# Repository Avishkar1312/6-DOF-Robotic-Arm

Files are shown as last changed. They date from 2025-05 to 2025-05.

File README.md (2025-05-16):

# 6-DOF Robotic Arm &#x1F916;

A robotic arm with 6 degrees of freedom made out of 3D printed parts. The software stack is primarily present in a Docker container setup in Raspberry Pi OS. It consists of a ROS2 pipeline written in Python with some C++ code in the Arduino IDE for controlling the stepper motors.

## Current Functionality:

* Currently only kinematic control has been established
* Individual joint angles can be altered using the Joint_State_Publisher_Gui and the respective changes in the configuration can be seen in the 3d model on Rviz2
* The desired joint angles can then be passed on to the hardware by pressing the "Enter" button in the GUI
* The hardware model receives the joint angles and aligns itself to match the configuration of the 3D model visualised in RViz

## Flow Chart:

Flowchart

## Pic of the model:

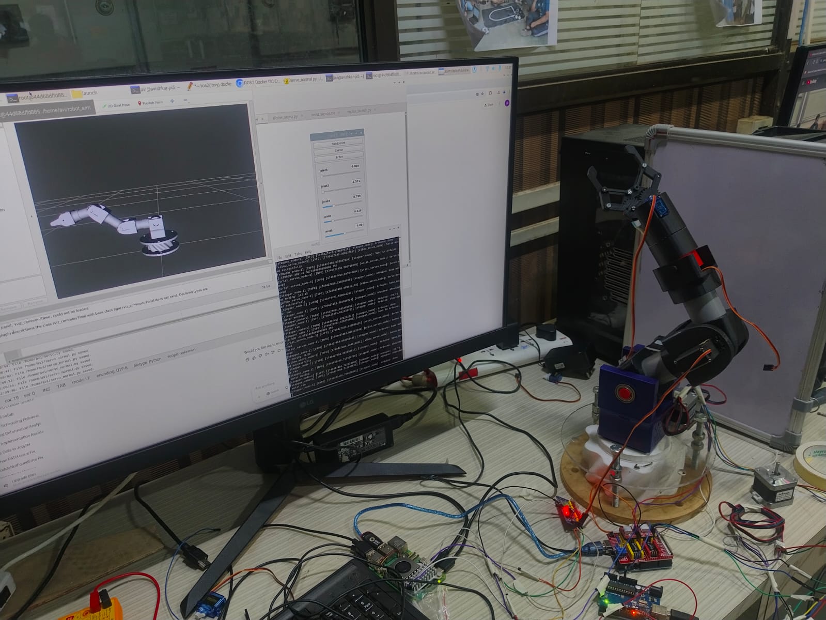
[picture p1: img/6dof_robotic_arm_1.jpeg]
Hardware model


## Softwares Used:

* SolidWorks
* Docker
* Raspberry Pi 5 OS
* Arduino IDE
* ROS2 Foxy
* RViz2

## Steps to replicate this identical model:

### I. CAD Model:

SolidWorks was used for creating the individual parts and assembling them together. If you want to use an identical model the cad files for all the individual parts and the assembly is present in the [Cad_files](Cad_files/) folder.

#### References used for modelling:

[RoTechnic Playlist](https://www.youtube.com/@roTechnic/playlists)

[Cycloidal Gear design](https://ewhiteowls.com/2022/02/the-ultimate-guide-to-design-cycloidal-drives-the-beating-heart-of-robotic-arms/)

[Modelling the robotic arm](https://www.youtube.com/playlist?list=PLeEzO_sX5H6TBD6EMGgV-qdhzxPY19m121)

After you have assembled it on SolidWorks, you will have to assign the proper coordinate frames to each joint(Tutorial for this is present in the references).

Once everything in  modelling is done, we will generate a URDF file for the model. For this, use the [Solidworks to URDF Converter](https://wiki.ros.org/sw_urdf_exporter) which will create a ROS package with your model in it.

We ultimately want a ROS2 package so we would use this application to convert it into a ROS2 package 

[ROS2 URDF Converter](https://wiki.ros.org/sw_urdf_exporter)

### II. Setting up Pi Environment:

Use Raspberry Pi Imager to flash the Raspberry Pi 5 OS image onto a USB drive. Then insert the USB into the Raspberry Pi 5 to boot from it
Configure the Pi accordingly. Some key configuration steps to follow:

1. Go into Raspi-Config
2. Enable SSH, VNC, and I2C
3. Enable the serial hardware port
4. Change the forwarding from Wayland to X11

#### Clone the repo:

```bash
git clone https://github.com/Avishkar1312/6-DOF-Robotic-Arm.git
```

#### Go into the folder and build the Docker image

```bash
docker build -t your-image-name .  #Keep the name according to your choice
```
### III. Running the simulation:

#### In one terminal run 

```bash
xhost +local:root
```
This command allows the root user to access the X server. This would be essential to see the GUI output of Rviz2 on the screen.

#### In another terminal, go into your work folder(in this case)

```bash
cd 6-DOF-Robotic-Arm-main 
```

#### Run the container:

> ⚠️ **Disclaimer:** Connect the Arduino with Raspberry Pi5 before running the command
```bash
docker run -it --rm --env DISPLAY=:0 --volume /tmp/.X11-unix:/tmp/.X11-unix --volume /path/on/host:/path/in/container --device /dev/ttyACM0 your_container_name
```

#### Navigate to the working directory and source the ros2 environment

```bash
source /opt/ros/foxy/setup.bash
```

#### Build the packages

```bash
colcon build 
```
This will create install,build and log folders in your workspace

#### Source the workspace 

```bash
source install/setup.bash
```
#### Launch the GUI and RViz window

```bash
ros2 launch final_arm_urdf launch.py 
```

You would now be able to interact with the simulation using the Joint_State_Publisher_GUI

### IV. Setting up the circuit connections

For the circuit diagrams, follow the images given in the [Circuit_diagrams](Circuit_diagrams/) folder. Copy the code given in the [Arduino_codes](Arduino_codes/) folder and paste it into your Arduino IDE. Upload this code into your respective Arduino.

After completing the circuit and connecting the motors, follow the further instructions to run the motor

1. Execute the steps of part III. (running the simulation) same as mentioned
2. Open a new terminal and go into the Docker container

```bash
docker ps 
```
Then copy the generated container id and use it in 

```bash
docker exec -it <container_id> bash # Paste your container id 
```

This will take you to the same container. Now navigate again to your workspace and source it. After all this, run the following command

```bash
ros2 launch raspi motor_launch.py
```
This will launch the nodes for each motor at once.

The hardware model is also ready to be executed. On pressing the "Enter" button on the GUI the specific configuration joint angles would be passed onto the hardware.

## Hardware Configuration:

| Joint | Gear type & Ratio | Motor |
|---|---|---|
| Base Joint | Cycloidal Gear (1:10) | NEMA 17 Stepper motor |
| Shoulder Joint | Snug fit(1:3.71) | NEMA 17 Stepper motor with gearbox |
| Elbow Joint | Snug Fit( Internal gears in servo)(1:1) | Metal geared servo motor |
| Wrist joints(3) | Snug Fit( Internal gears in servo)(1:1) | Plastic geared servo motor |

## Future Work to be done:

* Dynamic control is to be added
* Thinking of venturing into upper-level control, such as voice control.

## Open for more suggestions

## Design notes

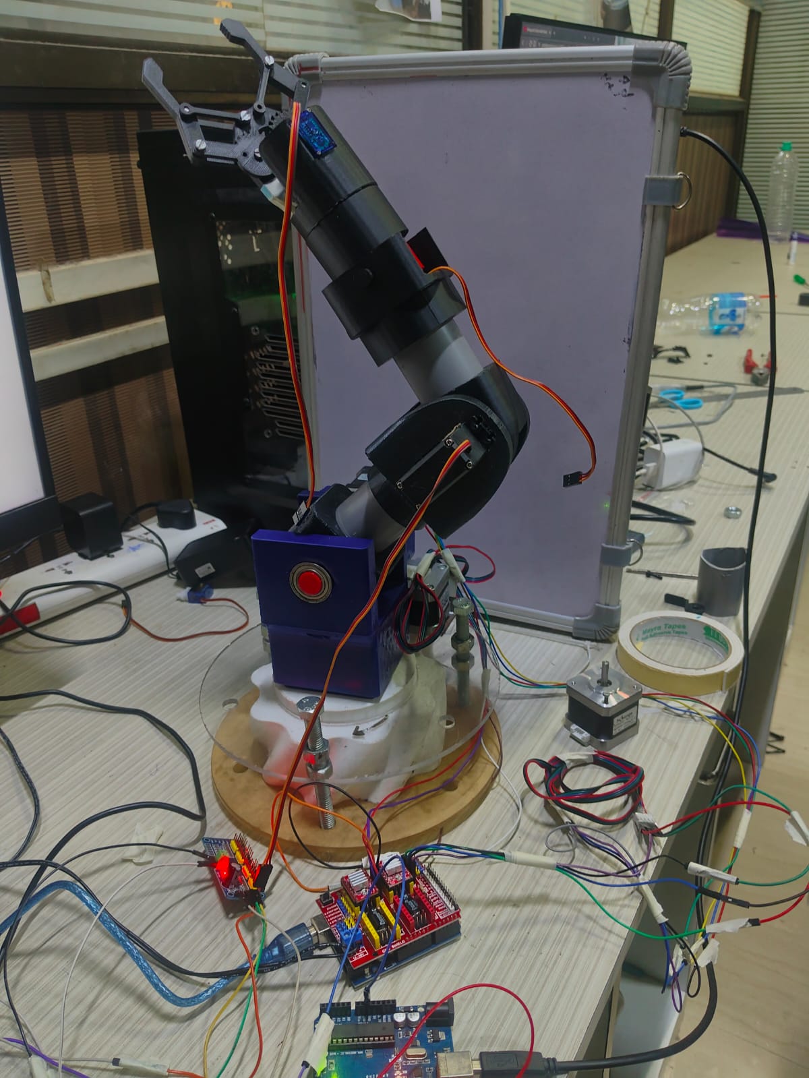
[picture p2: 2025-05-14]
img/6dof_robotic_arm_2.jpeg

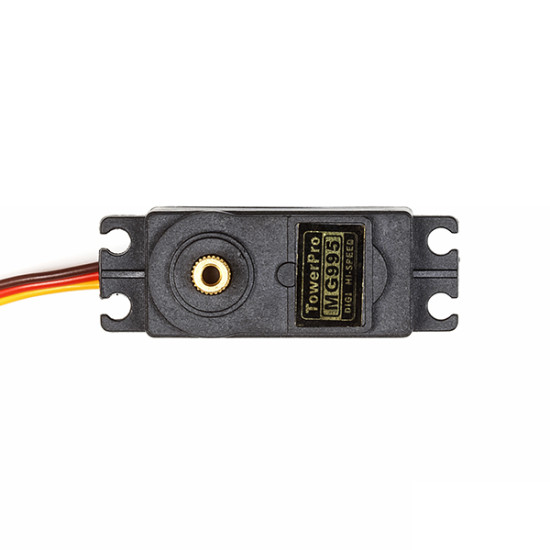
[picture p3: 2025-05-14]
img/servo_shoulder.jpg

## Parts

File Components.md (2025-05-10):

## Components List

| Component | Image | Quantity | Price  | Link |
|---|---|---|---|---|
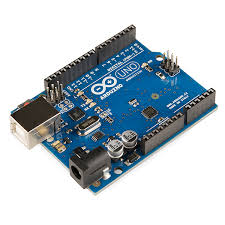
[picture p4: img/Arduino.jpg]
| Arduino Uno |  | 1 | ₹517  | [Buy](https://robu.in/product/arduino-uno-r3/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) |
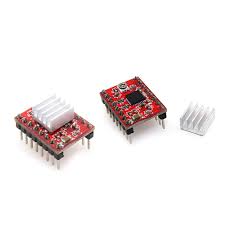
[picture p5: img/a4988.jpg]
| A4988 Stepper Driver|  | 2 | ₹61 | [Buy](https://robu.in/product/a4988-driver-stepper-motor-driver-standard-quality/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) |
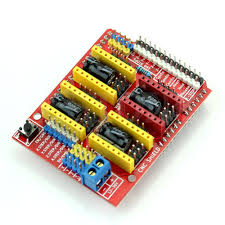
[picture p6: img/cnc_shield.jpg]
| CNC Shield V3 |  | 1 | ₹110 | [Buy](https://robu.in/product/cnc-shield-v3-engraving-machine-3d-printer-a4988-drv8825-driver-expansion-board/) |
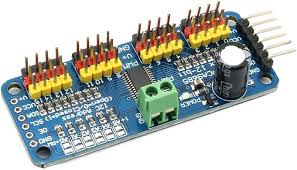
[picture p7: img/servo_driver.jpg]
| Servo Driver(PCA9685) |  | 1 | ₹228 | [Buy](https://robu.in/product/16-channel-12-bit-pwmservo-driver-i2c-interface-pca9685-arduino-raspberry-pi/) |
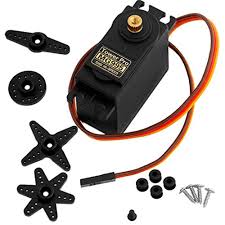
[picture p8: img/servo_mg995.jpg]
| Servo MG995(360 degrees) |  | 1 | ₹620 | [Buy](https://www.amazon.in/Robodo-TowerPro-MG995-Continuous-rotation/dp/B07DDKMM3J) |
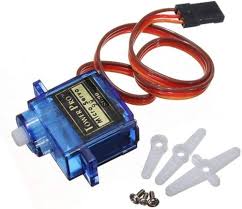
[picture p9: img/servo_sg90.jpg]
| Servo SG90(180 degrees) |  | 3 | ₹870 | [Buy](https://robu.in/product/towerpro-sg90-9g-mini-servo-9-gram/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) |
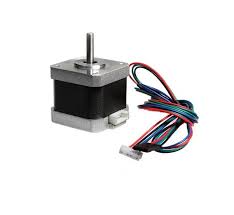
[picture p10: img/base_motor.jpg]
| Stepper motor (NEMA 17) |  | 1 | ₹681 | [Buy](https://robu.in/product/nema17-pr42hs40-1204af-02-4-2kg-cm-stepper-motor-d-type-shaft/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) |
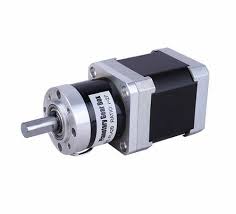
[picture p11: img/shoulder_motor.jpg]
| Stepper motor (NEMA 17-Gerabox(1:3.71)) |  | 1 | ₹3249 | [Buy](https://thinkrobotics.com/products/nema-17-planetary-gear-stepper-motor-100-1?variant=39604954693718) |
| Raspberry Pi5 8GB RAM |  | 1 | ₹8209 | [Buy](https://robu.in/product/raspberry-pi-5-model-8gb/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) |
| Raspi5 Heatsink |  | 1 | ₹456 | [Buy](https://robu.in/product/official-raspberry-pi-5-active-cooler/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) |
| Raspberry Pi5 Charger |  | 1 | ₹1149 | [Buy](https://robu.in/product/official-27w-usb-c-pd-power-supply-for-raspberry-pi-5-black/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) |
| USB(32GB) |  | 1 | ₹359 | [Buy](https://www.amazon.in/SanDisk-Cruzer-Blade-Flash-Drive/dp/B005FYNT3G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) |
| HDMI to Micro-USB |  | 1 | ₹451 | [Buy](https://www.flipkart.com/darahs-micro-usb-cable-1-4-m-high-speed-hdmi-not-micro-usb-ethernet-1-4-meter/p/itm2af90483b95cd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) |
| 12V Adapter |  | 1 | ₹180 | [Buy](https://robocraze.com/products/12-volt-2-amp-power-adapter-ac-to-dc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) |
| Silicon Grease |  | 1 | ₹265 | [Buy](https://www.amazon.in/TetraClean-Dielectric-Automotive-Electricals-Electrical/dp/B08R3NXT3B) |
| Ball Bearing(15x28x7) |  | 2 | ₹209(for 4) | [Buy](https://robu.in/product/6902zz-bearing-15x28x7-shielded-miniature-ball-bearings-4pcs/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) |
| Jumper wires |  | 1 | ₹107 | [Buy](https://robu.in/product/male-to-female-jumper-wires-40-pin-40cm/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) |
| 3-D Printing Filament (PLA) |  | ... | ₹891 | [Buy](https://robu.in/product/pro-range-pla-filament-1-75mm-1-kg-spool-black/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) |

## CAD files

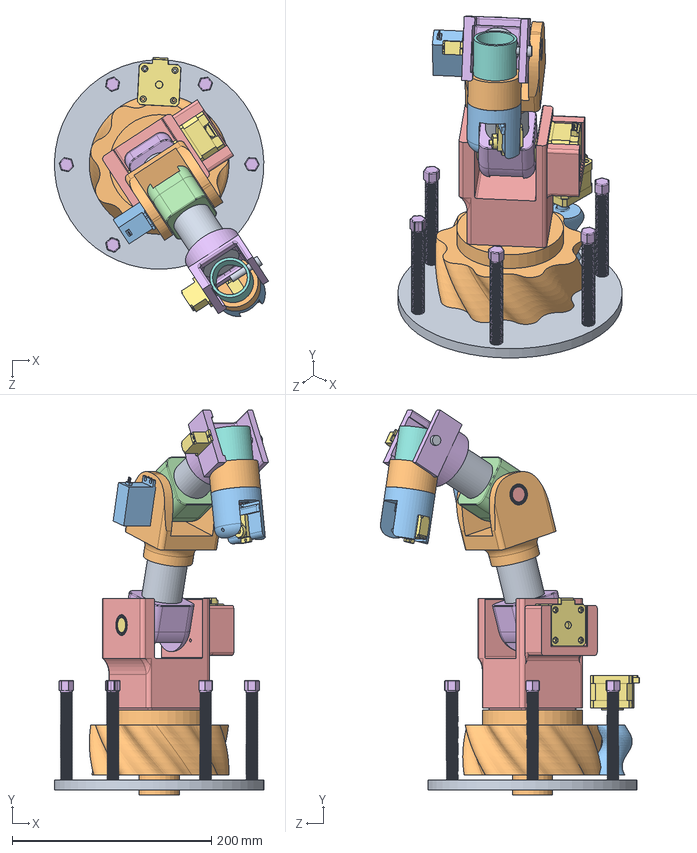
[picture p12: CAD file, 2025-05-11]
Cad_files/Robotic_Arm_final.SLDASM
214.6 x 386.0 x 259.9 mm
base_bottom
large_gear
small_gear
bottomstud
shoulder_mock1
final_shoulder
plug
instrument ball bearing_68_am x 2
arm x 2
elbow
mg995
elbow_extn_final
elbow_plug
wristholder
Servo SG90 x 3
pinpin
wrist _rotation_lid
blue_servo_mod_teeth
[4145] TowerPro SG90 Mini Servo-SunRobotics_in-Pt4
screw x 7
NEMA_17 x 2

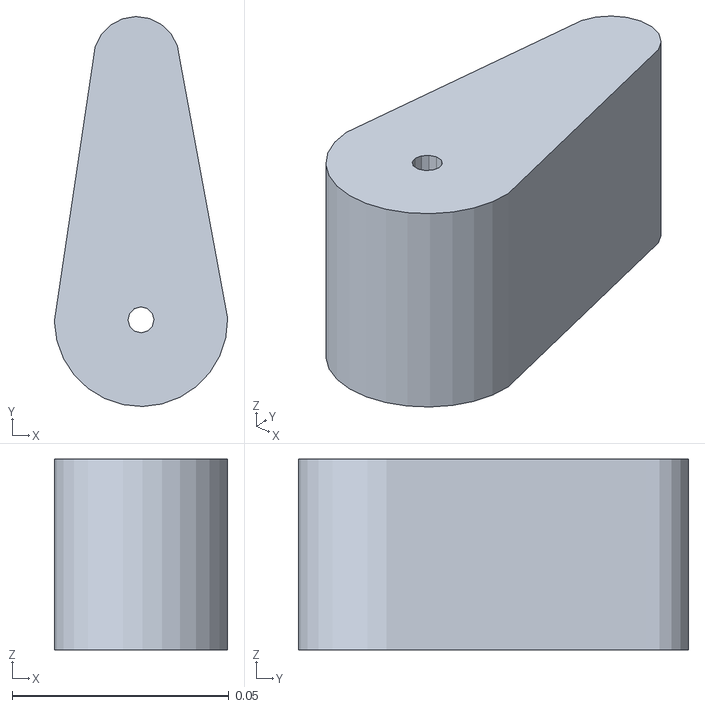
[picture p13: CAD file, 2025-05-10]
src/final_arm_urdf/meshes/collision/link5.STL
0.04 x 0.09 x 0.044

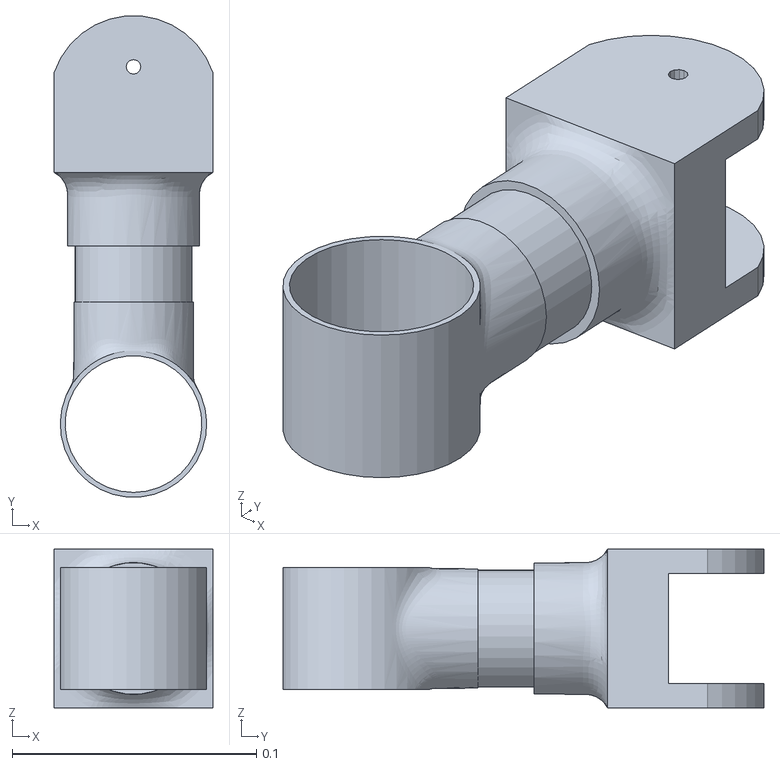
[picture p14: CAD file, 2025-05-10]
src/final_arm_urdf/meshes/visual/link4.STL
0.065 x 0.197 x 0.065

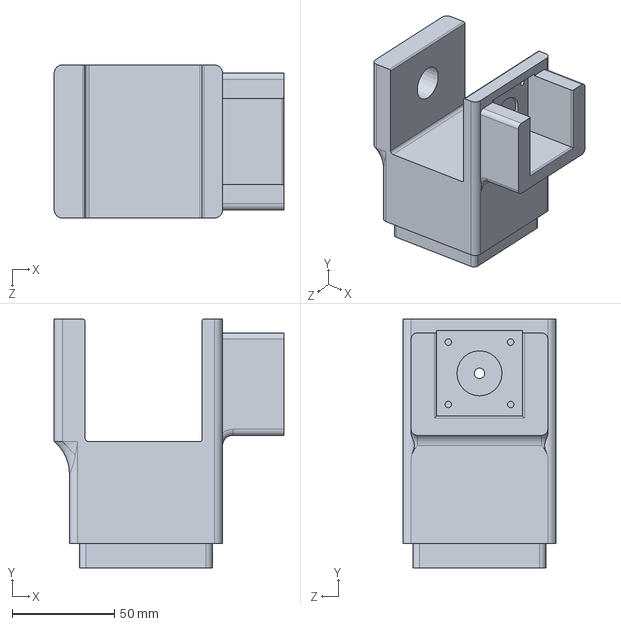
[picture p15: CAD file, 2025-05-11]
Cad_files/shoulder_mock1.SLDPRT
112.5 x 122.0 x 75.0 mm

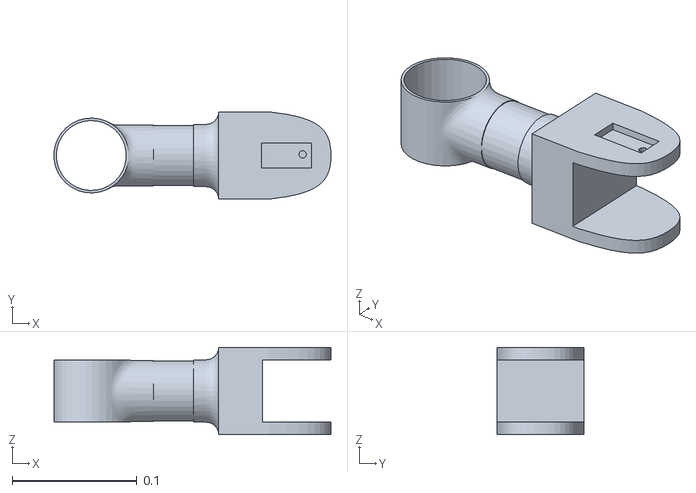
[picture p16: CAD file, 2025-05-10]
src/final_arm_urdf/meshes/collision/link3.STL
0.222 x 0.07 x 0.07

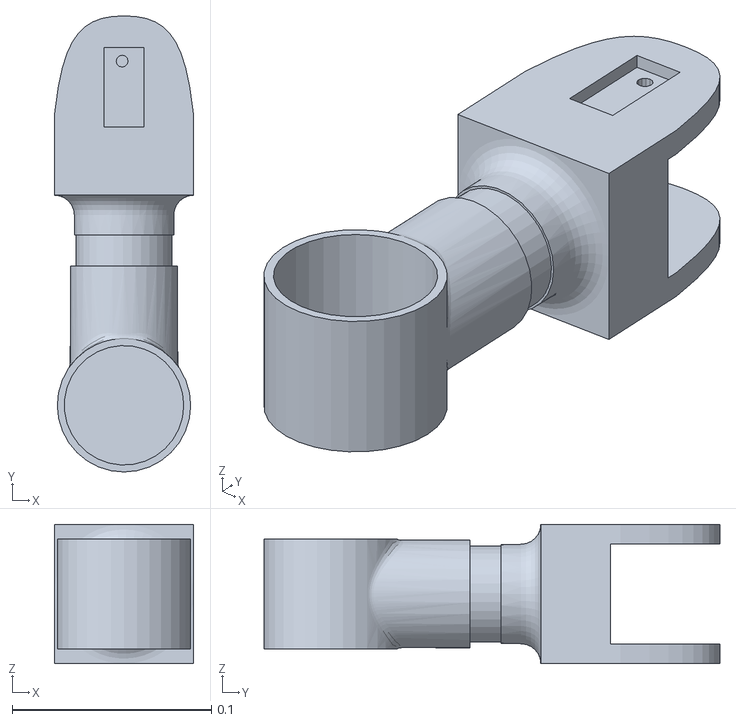
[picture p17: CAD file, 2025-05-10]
src/final_arm_urdf/meshes/visual/link2.STL
0.07 x 0.229 x 0.07

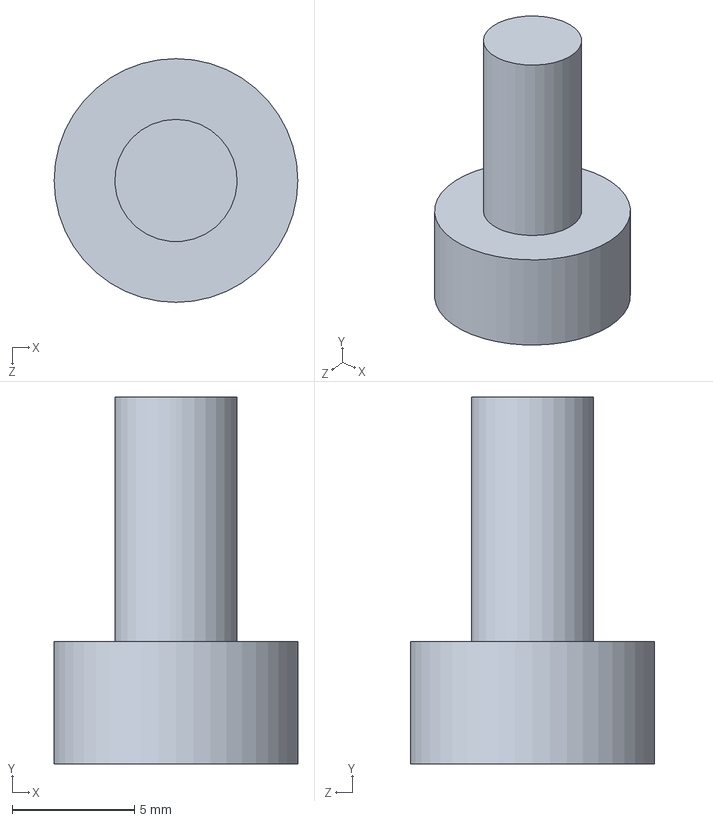
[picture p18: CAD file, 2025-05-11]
Cad_files/bottomstud.SLDPRT
9.96 x 15.0 x 9.96 mm

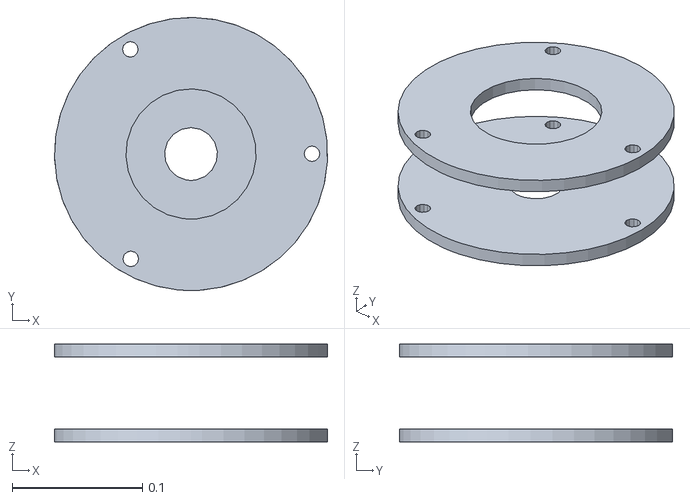
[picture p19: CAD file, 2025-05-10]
src/final_arm_urdf/meshes/collision/base_link.STL
0.21 x 0.21 x 0.075

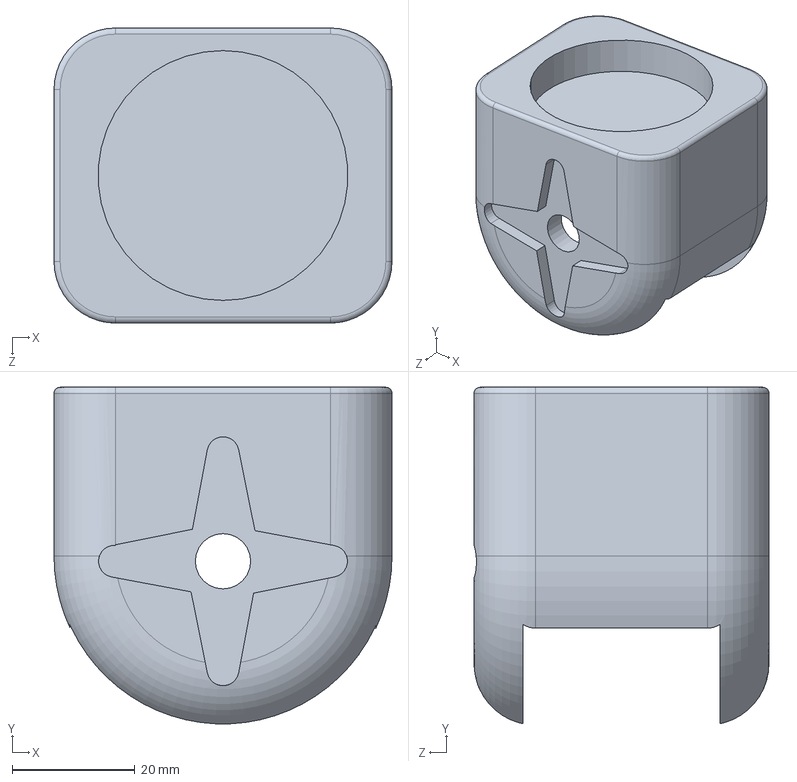
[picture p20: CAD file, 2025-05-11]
Cad_files/elbow_extn_final.SLDPRT
55.0 x 54.8 x 48.0 mm

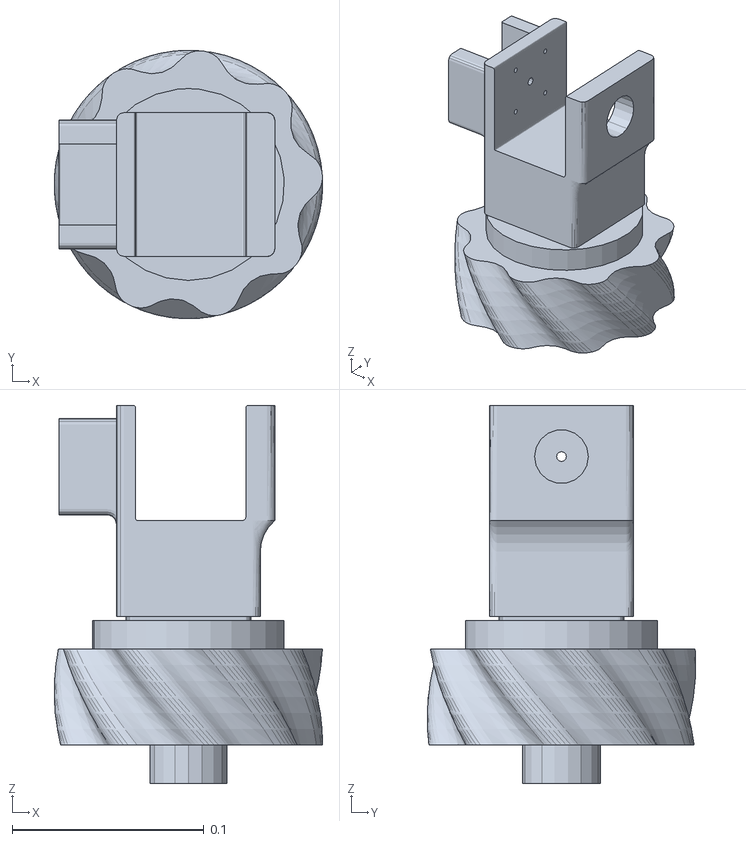
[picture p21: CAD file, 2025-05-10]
src/final_arm_urdf/meshes/visual/link1.STL
0.14 x 0.14 x 0.197

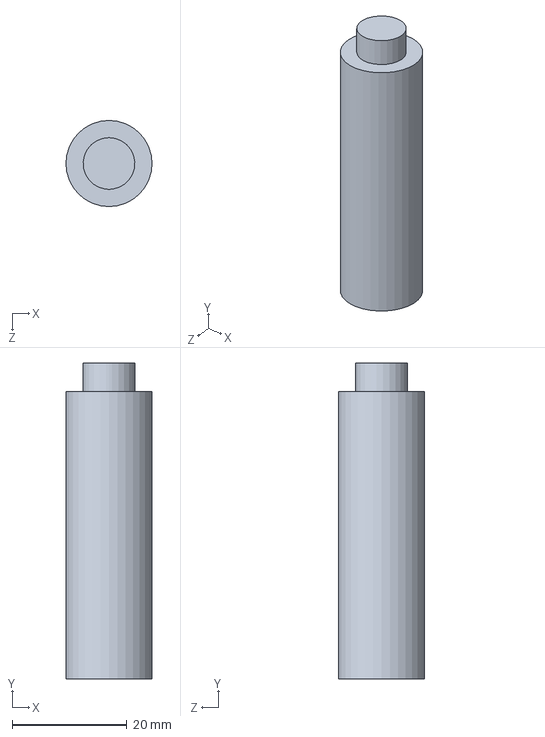
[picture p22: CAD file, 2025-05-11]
Cad_files/elbow_plug.SLDPRT
15.0 x 55.0 x 15.0 mm

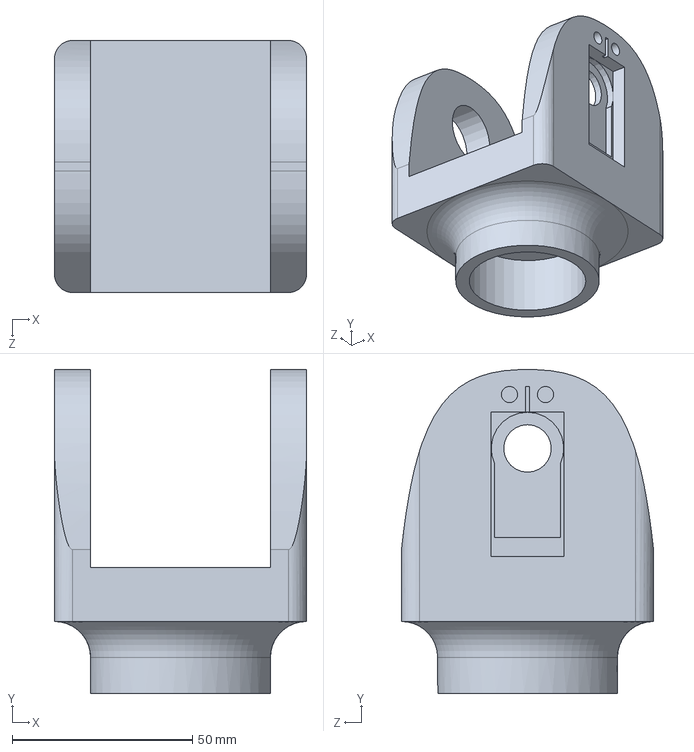
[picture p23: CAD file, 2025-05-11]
Cad_files/elbow.SLDPRT
70.0 x 90.0 x 70.0 mm

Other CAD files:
Cad_files/NEMA_17.SLDPRT
Cad_files/Part7.SLDPRT
Cad_files/Part9.SLDPRT
Cad_files/Servo SG90.SLDPRT
Cad_files/[4145] TowerPro SG90 Mini Servo-SunRobotics_in-Pt4.SLDPRT
Cad_files/arm.SLDPRT
Cad_files/base_bottom.SLDPRT
Cad_files/basetop.SLDPRT
Cad_files/blue_servo_mod_teeth.SLDPRT
Cad_files/final_shoulder.SLDPRT
Cad_files/gripper.SLDPRT
Cad_files/instrument ball bearing_68_am.sldprt
Cad_files/large_gear.SLDPRT
Cad_files/mg995.SLDPRT
Cad_files/mg995.stp
Cad_files/nut.SLDPRT
Cad_files/pinpin.SLDPRT
Cad_files/plug.SLDPRT
Cad_files/screw.SLDPRT
Cad_files/small_gear.SLDPRT
Cad_files/wrist _rotation_lid.SLDPRT
Cad_files/wristholder.SLDPRT

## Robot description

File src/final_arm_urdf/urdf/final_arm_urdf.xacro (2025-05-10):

<robot name="final_arm_urdf">

  <link name="base_link">
    <inertial>
      <origin xyz="-1.2317E-16 -2.498E-16 0.028906" rpy="0 0 0" />
      <mass value="0.59426" />
      <inertia ixx="0.0018342" ixy="-8.7929E-18" ixz="-2.6015E-19" iyy="0.0018342" iyz="1.9519E-19" izz="0.0036586" />
    </inertial>
    <visual>
      <origin xyz="0 0 0" rpy="0 0 0" />
      <geometry>
        <mesh filename="package://final_arm_urdf/meshes/visual/base_link.STL" />
      </geometry>
      <material name="">
        <color rgba="0.79216 0.81961 0.93333 1" />
      </material>
    </visual>
    <collision>
      <origin xyz="0 0 0" rpy="0 0 0" />
      <geometry>
        <mesh filename="package://final_arm_urdf/meshes/collision/base_link.STL" />
      </geometry>
    </collision>
  </link>
  <link name="link1">
    <inertial>
      <origin xyz="-0.0011483 1.4724E-06 0.061573" rpy="0 0 0" />
      <mass value="1.2427" />
      <inertia ixx="0.0017137" ixy="-2.8848E-09" ixz="4.6536E-05" iyy="0.00189" iyz="1.4625E-08" izz="0.0021854" />
    </inertial>
    <visual>
      <origin xyz="0 0 0" rpy="0 0 0" />
      <geometry>
        <mesh filename="package://final_arm_urdf/meshes/visual/link1.STL" />
      </geometry>
      <material name="">
        <color rgba="0.79216 0.81961 0.93333 1" />
      </material>
    </visual>
    <collision>
      <origin xyz="0 0 0" rpy="0 0 0" />
      <geometry>
        <mesh filename="package://final_arm_urdf/meshes/collision/link1.STL" />
      </geometry>
    </collision>
  </link>
  <joint name="joint1" type="revolute">
    <origin xyz="0 0 0" rpy="0 0 0" />
    <parent link="base_link" />
    <child link="link1" />
    <axis xyz="0 0 1" />
    <limit lower="0" upper="6.284" effort="300" velocity="3" />
    <calibration rising="0" falling="6.284" />
    <dynamics damping="0" friction="0" />
    <safety_controller soft_upper_limit="6.284" soft_lower_limit="0" k_position="0" k_velocity="0" />
  </joint>
  <link name="link2">
    <inertial>
      <origin xyz="7.0526E-07 0.092011 -0.029204" rpy="0 0 0" />
      <mass value="0.45196" />
      <inertia ixx="0.0004059" ixy="-7.0028E-09" ixz="-4.6156E-09" iyy="0.00031391" iyz="-3.6133E-06" izz="0.0003795" />
    </inertial>
    <visual>
      <origin xyz="0 0 0" rpy="0 0 0" />
      <geometry>
        <mesh filename="package://final_arm_urdf/meshes/visual/link2.STL" />
      </geometry>
      <material name="">
        <color rgba="0.79216 0.81961 0.93333 1" />
      </material>
    </visual>
    <collision>
      <origin xyz="0 0 0" rpy="0 0 0" />
      <geometry>
        <mesh filename="package://final_arm_urdf/meshes/collision/link2.STL" />
      </geometry>
    </collision>
  </link>
  <joint name="joint2" type="revolute">
    <origin xyz="0.0275 0 0.15538" rpy="1.5708 0 1.5708" />
    <parent link="link1" />
    <child link="link2" />
    <axis xyz="0 0 -1" />
    <limit lower="-1.571" upper="1.571" effort="300" velocity="3" />
    <calibration rising="0" falling="1.571" />
    <dynamics damping="0" friction="0" />
    <safety_controller soft_upper_limit="1.571" soft_lower_limit="-1.571" k_position="0" k_velocity="0" />
  </joint>
  <link name="link3">
    <inertial>
      <origin xyz="0.10219 -3.8224E-07 -0.025347" rpy="0 0 0" />
      <mass value="0.38558" />
      <inertia ixx="0.00026816" ixy="6.2277E-09" ixz="3.6385E-06" iyy="0.00032917" iyz="3.0322E-09" izz="0.00029965" />
    </inertial>
    <visual>
      <origin xyz="0 0 0" rpy="0 0 0" />
      <geometry>
        <mesh filename="package://final_arm_urdf/meshes/visual/link3.STL" />
      </geometry>
      <material name="">
        <color rgba="0.79216 0.81961 0.93333 1" />
      </material>
    </visual>
    <collision>
      <origin xyz="0 0 0" rpy="0 0 0" />
      <geometry>
        <mesh filename="package://final_arm_urdf/meshes/collision/link3.STL" />
      </geometry>
    </collision>
  </link>
  <joint name="joint3" type="revolute">
    <origin xyz="-0.00093484 0.17284 -0.0025" rpy="0 0 0" />
    <parent link="link2" />
    <child link="link3" />
    <axis xyz="0 0 1" />
    <limit lower="0" upper="3.142" effort="300" velocity="3" />
    <calibration rising="0" falling="3.142" />
    <dynamics damping="0" friction="0" />
    <safety_controller soft_upper_limit="3.142" soft_lower_limit="0" k_position="0" k_velocity="0" />
  </joint>
  <link name="link4">
    <inertial>
      <origin xyz="-2.4945E-06 0.090846 -0.024558" rpy="0 0 0" />
      <mass value="0.3087" />
      <inertia ixx="0.00021105" ixy="1.2263E-08" ixz="-2.3037E-08" iyy="0.0001769" iyz="-2.0811E-06" izz="0.00019916" />
    </inertial>
    <visual>
      <origin xyz="0 0 0" rpy="0 0 0" />
      <geometry>
        <mesh filename="package://final_arm_urdf/meshes/visual/link4.STL" />
      </geometry>
      <material name="">
        <color rgba="0.79216 0.81961 0.93333 1" />
      </material>
    </visual>
    <collision>
      <origin xyz="0 0 0" rpy="0 0 0" />
      <geometry>
        <mesh filename="package://final_arm_urdf/meshes/collision/link4.STL" />
      </geometry>
    </collision>
  </link>
  <joint name="joint4" type="revolute">
    <origin xyz="0.16934 0.00093484 0" rpy="0 0 0" />
    <parent link="link3" />
    <child link="link4" />
    <axis xyz="0 0 -1" />
    <limit lower="0" upper="3.142" effort="300" velocity="3" />
    <calibration rising="0" falling="3.142" />
    <dynamics damping="0" friction="0" />
    <safety_controller soft_upper_limit="3.142" soft_lower_limit="0" k_position="0" k_velocity="0" />
  </joint>
  <link name="link5">
    <inertial>
      <origin xyz="-0.0003626 0.020629 -0.033" rpy="0 0 0" />
      <mass value="0.11251" />
      <inertia ixx="8.0778E-05" ixy="9.3321E-07" ixz="3.4347E-21" iyy="2.7703E-05" iyz="-4.5715E-21" izz="7.2177E-05" />
    </inertial>
    <visual>
      <origin xyz="0 0 0" rpy="0 0 0" />
      <geometry>
        <mesh filename="package://final_arm_urdf/meshes/visual/link5.STL" />
      </geometry>
      <material name="">
        <color rgba="0.79216 0.81961 0.93333 1" />
      </material>
    </visual>
    <collision>
      <origin xyz="0 0 0" rpy="0 0 0" />
      <geometry>
        <mesh filename="package://final_arm_urdf/meshes/collision/link5.STL" />
      </geometry>
    </collision>
  </link>
  <joint name="joint5" type="revolute">
    <origin xyz="0 0.14633 0.0075" rpy="0 0 0" />
    <parent link="link4" />
    <child link="link5" />
    <axis xyz="0 0 1" />
    <limit lower="-1.571" upper="1.571" effort="300" velocity="3" />
    <calibration rising="0" falling="1.571" />
    <dynamics damping="0" friction="0" />
    <safety_controller soft_upper_limit="1.571" soft_lower_limit="-1.571" k_position="0" k_velocity="0" />
  </joint>
</robot>

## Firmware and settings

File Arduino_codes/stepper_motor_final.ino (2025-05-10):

#include <AccelStepper.h>

#define STEP_PIN_M1 2    //Step pin of Base_Motor
#define DIR_PIN_M1 5     //Direction pin of Base_Motor
#define STEP_PIN_M2 3    //Step pin of Shoulder_Motor
#define DIR_PIN_M2 6     //Direction pin ofShoulder_Motor  
#define En_Pin1 8  //Assigning a name to the unified enable pin of all the stepper drivers on the cnc shield


AccelStepper stepperM1(AccelStepper::DRIVER, STEP_PIN_M1, DIR_PIN_M1);      //Defining Base_motor
AccelStepper stepperM2(AccelStepper::DRIVER, STEP_PIN_M2, DIR_PIN_M2);      //Defining Shoulder_motor

String input = "";

void setup() {
  Serial.begin(9600);
  pinMode(En_Pin1,OUTPUT);
  digitalWrite(En_Pin1,LOW);   // Making the unified enable pin low so that all stepper drivers are functional
  stepperM1.setAcceleration(500);    /// these values are set to smoothen the position and to avoid any jittery consequences
  stepperM1.setMaxSpeed(400); // default
  stepperM2.setAcceleration(500);
  stepperM2.setMaxSpeed(400); // default
}

void loop() {                           // Used to read the incoming serial outputs from the raspi5
  if (Serial.available()) {
    char c = Serial.read();
    if (c == '\n') {
      parseCommand(input);
      input = "";
    } else {
      input += c;
    }
  }


  stepperM1.run();                     //Keeps the current running in the base_motor so that it holds its position
  stepperM2.run();                     //Keeps the current running in the shoulder_motor so that it holds its position
}

void parseCommand(String cmd) {                                //Used to parse the incoming angle and speed commands from teh raspi5
  cmd.trim();

  int firstSpace = cmd.indexOf(' ');
  int secondSpace = cmd.indexOf(' ', firstSpace + 1);
  int thirdSpace = cmd.indexOf(' ', secondSpace + 1);


  float angle1 = cmd.substring(0, firstSpace).toFloat();
  float speed1 = cmd.substring(firstSpace + 1, secondSpace).toFloat();
  float angle2 = cmd.substring(secondSpace + 1, thirdSpace).toFloat();
  float speed2 = cmd.substring(thirdSpace + 1).toFloat();
  base_Motor(angle1,speed1);
  shoulder_Motor(angle2,speed2);


  }


void base_Motor(float angle1,float speed1) {
  stepperM1.moveTo(angleToSteps(angle1*10*180/3.14));            // 180/3.14 is used to convert the angle from radians to degrees
  Serial.print("base motor moving: ");                           //angle1 is multiplied by 10 as the gear ratio of the bottom gear is 10
  Serial.println(angle1*180/3.14);                               //Actual angle1 in degrees is printed

  
  while (stepperM1.isRunning()) {
    stepperM1.run();
  }

  Serial.println("base_motor ran");  
}

void shoulder_Motor(float angle2, float speed2){

  stepperM2.moveTo(angleToSteps(angle2*3.7*180/3.14));            // 180/3.14 is used to convert the angle from radians to degrees
  Serial.println("shoulder motor moving: ");                      //angle2 is multiplied by 3.7 as the gear ratio of the shoulder gearbox is 3.7
  Serial.println(angle2*180/3.14);                                //Actual angle2 in degrees is printed

  while(stepperM2.isRunning()){
    stepperM2.run();
  }
  Serial.println("shoulder motor ran");
  Serial.println("done");

}

int angleToSteps(float angle) {                                   //Steps for the motor are decided for the corresponding angle
  return angle / 1.8;                                             //Full Step mode
}

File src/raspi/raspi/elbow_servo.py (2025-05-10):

import rclpy
from rclpy.node import Node
from sensor_msgs.msg import JointState
from Adafruit_PCA9685 import PCA9685
#from adafruit_servokit import ServoKit
from time import sleep


class Servo_Subscriber(Node):
    def __init__(self):
        super().__init__('servo_subscriber')
        #self.kit =ServoKit(channels=16)
        self.get_logger().info("Initializing PCA9685")
        self.pwm=PCA9685(busnum=1)
        self.pwm.set_pwm_freq(60)
        self.get_logger().info("PCA9685 Initialized. Freq set to 60Hz")
        self.servo_subscriber=self.create_subscription(JointState,'/robo_angles',self.timer_callback,10)
        self.servo_subscriber


    def timer_callback(self,msg):
        current_elbow_angle=0
        desired_elbow_angle=msg.position[2]*180/3.14
        i=0
        step=2 if desired_elbow_angle >=0 else -5
        for angle in range (int(current_elbow_angle), int(desired_elbow_angle -current_elbow_angle)+step,step):
            self.pwm.set_pwm(0,0, self.angle_to_pulse(angle))
            sleep(0.02)
        self.pwm.set_pwm(0,0,0)
        current_elbow_angle=desired_elbow_angle
        self.get_logger().info("Servo moved successfully")
        """
        wrist_angle_roll=msg.position[3]
        wrist_angle_pitch=msg.position[4]
        wrist_angle_yaw=msg.position[5]
        """
        #self.get_logger().info("Hello")

    def angle_to_pulse(self,angle):
        pulse= int (375+(angle /90.0)*225)
        return max(150, min(pulse,600))

def main(args=None):
    rclpy.init(args=args)
    node=Servo_Subscriber()
    rclpy.spin(node)
    rclpy.shutdown()
        

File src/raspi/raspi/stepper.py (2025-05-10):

import rclpy
from rclpy.node import Node
from sensor_msgs.msg import JointState
import serial
import time

class Stepper_subscriber(Node):
    def __init__(self):
        super().__init__('jstepper_subscriber')

        self.arduino = serial.Serial('/dev/ttyACM0', 9600, timeout=1)
        time.sleep(2)
        self.stepper=self.create_subscription(JointState,'/robo_angles',self.timer_callback,10)
        self.stepper
 

    def timer_callback(self,msg):
        
        base_angle=msg.position[0]
        base_speed=300
        shoulder_angle=msg.position[1]
        shoulder_speed=150
        stepper_cmd=f"{base_angle} {base_speed} {shoulder_angle} {shoulder_speed}\n"
        self.arduino.write(stepper_cmd.encode())
        self.get_logger().info("Sent to Arduino: %s" % stepper_cmd.strip())

        while True:
            if self.arduino.in_waiting:
                updates=self.arduino.readline().decode().strip()
                self.get_logger().info("Arduino: %s" %updates)
                if "done" == updates.lower():
                    break


        #self.get_logger().info("Base: %d" %msg.position[0])


def main(args=None):
    rclpy.init(args=args)
    node=Stepper_subscriber()
    rclpy.spin(node)
    node.arduino.close()
    rclpy.shutdown()

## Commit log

2025-05-10 src packages' changes
    [base_link.STL, final_arm_urdf.xacro, link1.STL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]
2025-05-10 Arduino codes
2025-05-10 Servo codes
2025-05-11 Cad files
    [NEMA_17.SLDPRT, Part7.SLDPRT, Part9.SLDPRT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]
2025-05-14 Circuit connections
2025-05-14 Addition of the arm images
